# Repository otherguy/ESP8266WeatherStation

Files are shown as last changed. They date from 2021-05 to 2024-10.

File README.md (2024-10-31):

# 🌤 ESP8266 Weather Station

## Hardware

### Bill of Materials (BOM)

The following components are required (all through hole):

| Qty. | Item | Value | Label | Footprint | Price |
|---|---|---|---|---|---|
| 1 | ESP8266 NodeMCU v3 board (4MB flash) | - | | - | US$ 2.05 |
| 3 | MAX7219 8×8 SPI LED matrix | - | | - | US$ 3.14 |
| 1 | DC Female Power Socket | 5.5 × 2.1mm | `J1` | PTH | US$ 0.07 |
| 1 | Trimmer potentiometer | 3mm, 1kΩ | `R1` | DIP-3 PTH | US$ 0.04 |
| 1 | LED | green, 3mm | `LED1` | THT | US$ 0.02 |
| 1 | LED | yellow, 3mm | `LED2` | THT | US$ 0.02 |
| 1 | Resistor (axial) | 4.7kΩ, ¼W, ±5% | `R2` | THT | US$ 0.01 |
| 2 | Resistor (axial) | 100Ω, ¼W, ±5%  | `R3`, `R4` | THT | US$ 0.01 |

I used [RobotDyn yellow/amber colored modules](https://www.aliexpress.com/item/32732745628.html). A lot
of other modules will also work, but they need to be 5-pin SPI chainable modules. Be aware of the pinout!

For the ESP8266 board, I used a [KeyeStudio NodeMCU](https://www.aliexpress.com/item/32668574859.html) but any
other NodeMCU V2 or V3 board also works.

The knockoff V3 boards are better because they use a CH340 USB controller chip and have the `A0` pin reference
voltage set at `3.3V` instead of `1.0V`, meaning no voltage divider circuit is needed.

### Circuit Board

The circuit board is very simple and just holds the ESP8266 and the 3 LED matrices as
well as the power jack and a trimpot to adjust the LED brightness.

I had 10 boards (1.6mm FR4 ENIG, RoHS, black solder mask) manufactured by [JLPCB](https://jlcpcb.com) for
US$ 44.00 including shipping in April 2021. The black solder mask makes it easy to prevent reflections inside
the case (and it looks gorgeous).

The [Fritzing file](hardware/NodeMCUWeatherStation.fzz) as well as the exported
[Gerber files](hardware/NodeMCUWeatherStation_Gerber.zip) can be found in the [hardware](hardware) folder.

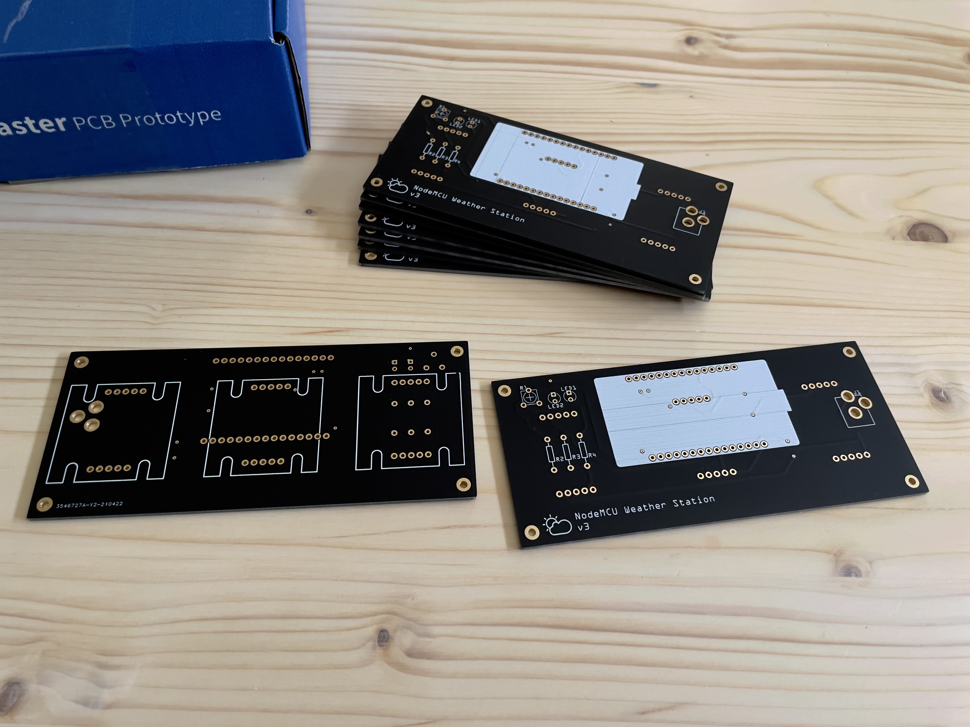
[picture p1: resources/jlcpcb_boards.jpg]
Finished PCB JLCPCB Finished PCB


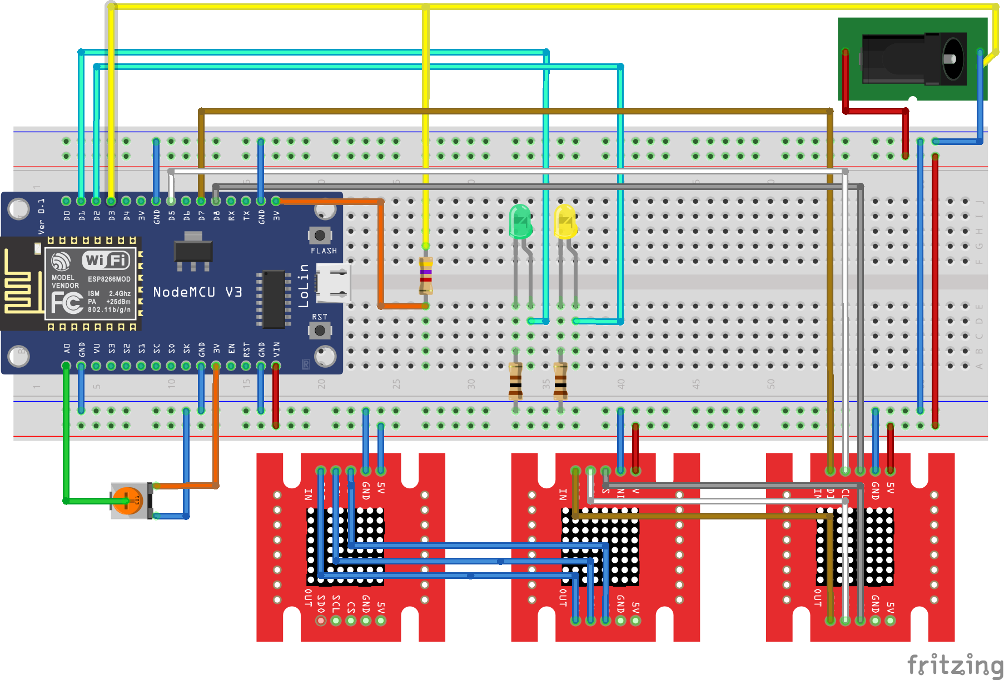
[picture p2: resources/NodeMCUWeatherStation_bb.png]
Breadboard View


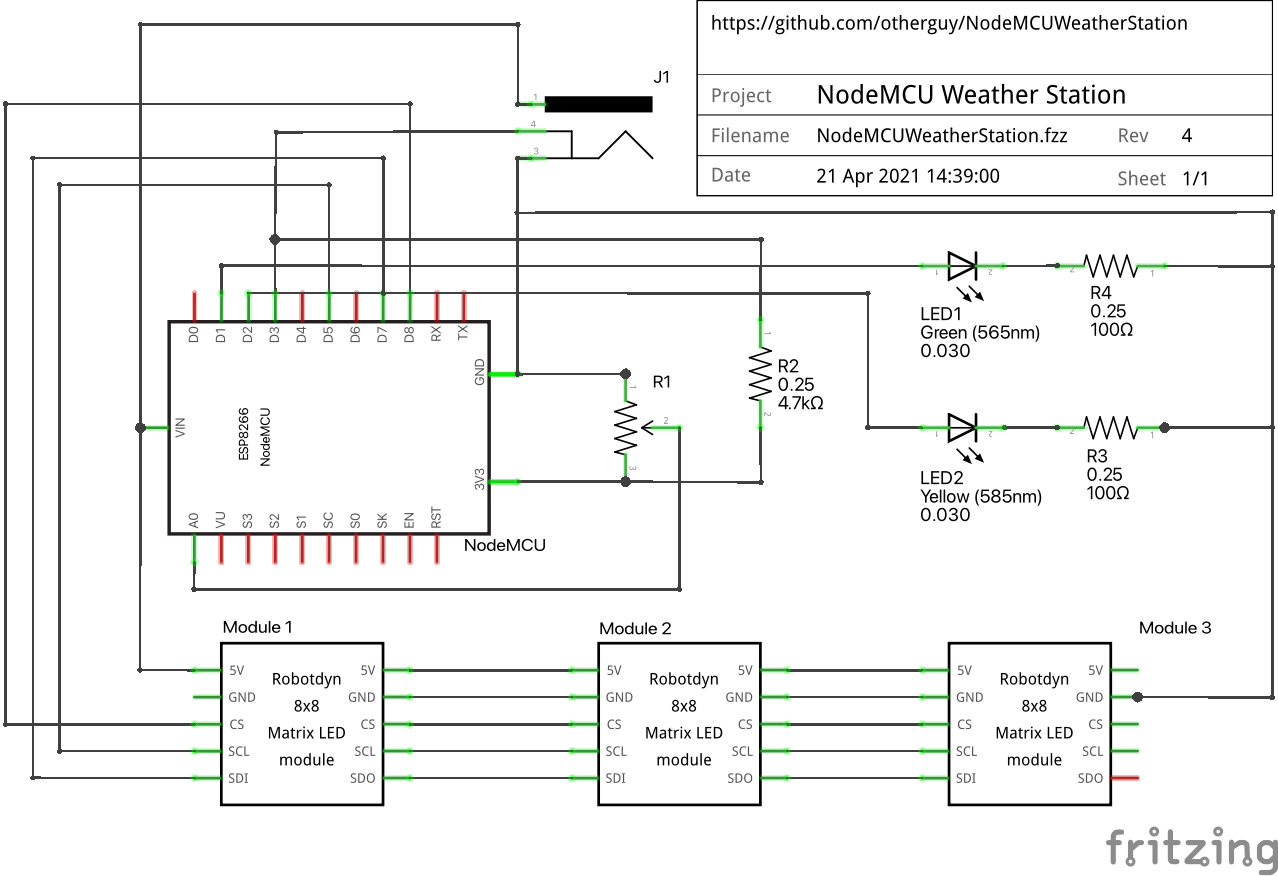
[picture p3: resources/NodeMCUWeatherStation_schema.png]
Schema View


The [`robotdyn-max7219-LED-matrix.fzpz`](hardware/robotdyn-max7219-LED-matrix.fzpz) Fritzing part was made
by [`@vanepp`](https://forum.fritzing.org/u/vanepp) on the Fritzing forums.

### Outer Case

[TBD]

## Software

### Prerequisites

Install [`esptool`](https://github.com/espressif/esptool) and [`ampy`](https://github.com/scientifichackers/ampy).

```bash
$ pip3 install --user esptool
$ pip3 install --user adafruit-ampy
```

### Install MicroPython

Download the latest [MicroPython firmware for ESP8266](https://micropython.org/download/esp8266/) and flash it to the NodeMCU.
[`esp8266-20220117-v1.18.bin`](firmware/esp8266-20220117-v1.18.bin) and flash it to the ESP8266.

_Note:_ Since July 2024, when using the OpenWeatherMap API, you need to use a custom build of MicroPython with a larger TLS buffer. See the section below for more details.

_Note:_ The USB serial device (`/dev/tty.usbserial-1430`) will be different, depending on your operating
system, USB controller and port you use.

```bash
$ esptool.py --port /dev/tty.usbserial-1430 erase_flash
$ esptool.py --port /dev/tty.usbserial-1430 --baud 460800 write_flash --flash_size=detect -fm dio 0x00 firmware/ESP8266_GENERIC-20240602-v1.24.0.bin
```

### Workaround for TLS buffer overflow in axtls

OpenWeatherMap switched to a new SSL certificate in July 2024 which is too large for the default buffer size in the ESP8266's MicroPython TLS implementation with axTLS. This causes the ESP8266 to crash when trying to fetch weather data.
To address this, the buffer size needs to be increased by recompiling the firmware with appropriate settings. More
details can be found in [this GitHub issue](https://github.com/micropython/micropython/issues/3279).

I have provided a precompiled firmware image with the necessary changes in the [firmware](firmware) folder. The firmware
is based on MicroPython `1.24.0` and has a larger TLS buffer size of 8192 bytes. Simply use the [`ESP8266_GENERIC-20240602-v1.24.0-tls-buffer-8192.bin`](firmware/ESP8266_GENERIC-20240602-v1.24.0-tls-buffer-8192.bin)
file instead of [`ESP8266_GENERIC-20240602-v1.24.0.bin`](firmware/ESP8266_GENERIC-20240602-v1.24.0.bin).

You can also compile the firmware for ESP8266 yourself with the following steps:

```bash
gh repo clone micropython/micropython
cd micropython
git checkout v1.24.0
make -C ports/esp8266 submodules
docker run --rm -v $HOME:$HOME -u $UID -w $PWD -e GIT_DISABLE_UNTRACKED_CACHE=1 larsks/esp-open-sdk make -j8 -C mpy-cross
cd ports/esp8266
docker run --rm -v $HOME:$HOME -u $UID -w $PWD -e GIT_DISABLE_UNTRACKED_CACHE=1 larsks/esp-open-sdk make -j8 AXTLS_DEFS_EXTRA="-Dabort=abort_ -DRT_MAX_PLAIN_LENGTH=1024 -DRT_EXTRA=8192" BOARD="ESP8266_GENERIC"
```

The firmware can then be found at `build-ESP8266_GENERIC/firmware.bin`.

### Configure Settings

Edit [`secrets.py`](src/secrets.py) and configure the values for your WiFi network (`WIFI_SSID` and `WIFI_PASSWORD`).

Next, sign up for a free account on [OpenWeather](https://openweathermap.org/), generate
[an API key](https://home.openweathermap.org/api_keys) and set it in the `OW_API_KEY` constant in [`secrets.py`](src/secrets.py).

Find the location you want to display weather data for on [OpenWeather](https://openweathermap.org/) and set the
`GEO_NAME`, `GEO_LAT` and `GEO_LON` constants in [`secrets.py`](src/secrets.py). `GEO_NAME` is not really used at the
moment, so it's only a reminder for you so you know what place you're looking at.

`DISPLAY_OFF_START` and `DISPLAY_OFF_END` are used to control when the display is turned off, e.g. at night. The value
is the hour in 24-hour format, in UTC. Adjust accordingly. If you're in New York City and you want the display to turn
off from 11pm to 7am, you might want to set `DISPLAY_OFF_START` to `3` and `DISPLAY_OFF_END` to `11`. Set both values
to `0` if you never want to turn off the display.

### Upload Software

Use [Adafruit's `ampy` tool](https://github.com/adafruit/ampy) to upload the software to the ESP8266. Adjust the
port according to your operating system and USB controller.

```bash
$ ampy --port /dev/tty.usbserial-1430 --baud 115200 put src/boot.py
$ ampy --port /dev/tty.usbserial-1430 --baud 115200 put src/max7219.py
$ ampy --port /dev/tty.usbserial-1430 --baud 115200 put src/symbols.py
$ ampy --port /dev/tty.usbserial-1430 --baud 115200 put src/secrets.py
$ ampy --port /dev/tty.usbserial-1430 --baud 115200 put src/main.py
```

## Other

### Trimmer Potentiometer

The trimmer potentiometer at `R1` is used to adjust the brightness of the display. The brightness is always
forced to be at the lowest value when the power jack is unplugged. Whe `DISPLAY_OFF_START` and `DISPLAY_OFF_END`
are set to any other value than `0`, the display will be turned off during the specified time period and the
potentiometer value is ignored.

### LEDs

`LED 1` is used to indicate network activity, while connecting to WiFi or fetching weather data.

`LED 2` is used for debugging purposes. It blinks every 2 seconds (or whatever you set in `BLINK_DELAY`). If it
does not blink, it means that the display is not updating and the ESP8266 has locked up.

### Weather Icons

The weather icons were custom designed using this excellent [LED Matrix Editor](https://git.io/J3N9M).

Weather Icons Custom Weather Icons: #185a66bddb663c00|894218bc3d184291|001ea1a919a6c0ec|00007e818999710e|152a547e8191710e|0a04087e8191710e|55aa55aa55aa55aa|a542a51818a542a5|180018183c3c1800|1800183860663c00

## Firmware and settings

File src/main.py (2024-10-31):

# -*- coding: utf-8 -*-
#
# main.py
#
from machine import Pin, Signal, SPI, reset, ADC
from utime import sleep, ticks_ms, localtime
from max7219 import Matrix8x8
from network import WLAN, STA_IF
from ntptime import settime
import secrets
import symbols
import urequests as requests
import gc

# #############################################################################
# ### Configuration
# #############################################################################
#
# This is fairly static and does not need to be changed when deploying.
#

# How often to check for weather updates (milliseconds)
QUERY_DELAY   = 1800000 # 30 minutes

# How often to blink the LED (milliseconds)
BLINK_DELAY   =   30000 # 30 seconds

# How many failed attempts to fetch weather before displaying an error
FAILURE_THRESHOLD = 5

# Definitions
NUM_MATRICES  = 3  # How many 8x8 matrices are connected
CS_PIN        = 15 # GPIO 15 = D8 = CS
LED_0_PIN     = 2  # GPIO  2 = internal LED of the ESP8266
LED_1_PIN     = 5  # GPIO  5 = D1
LED_2_PIN     = 4  # GPIO  4 = D2
INSERTION_PIN = 0  # GPIO  0 = D3
SPI_BAUDRATE  = 10000000 # 10Mhz baudrate (default is 80Mhz)

# #############################################################################
# #############################################################################
# #############################################################################

# Fn: remap()
def remap(value, out_min=0.0, out_max=1.0, in_min=0.0, in_max=1024.0):
    """
    Maps a value from a given range (default 0-1024) to a new
    range (default 0.0 - 1.0). Works with int and float values.

    :param value:    The value to remap
    :param out_min:  The lower end of the output range
    :param out_max:  The upper end of the output range
    :param in_min:   The lower end of the input range
    :param in_max:   The upper end of the output range

    :return: The remapped value
    """
    return float(min(out_max, max(out_min, (float(value) - in_min) * (out_max - out_min) / (in_max - in_min) + out_min)))

# Fn: set_matrix_brightness()
def set_matrix_brightness(pot, display, old_brightness_value, min_brightness=0, max_brightness=15):
    """
    Fetches the daily weather forecast for a given
    location from OpenWeatherMap.

    :param pot:                  The trim potentiometer object to read the analog value from
    :param display:              The LED matrix display object to set the brightness on
    :param old_brightness_value: The previous brightness value
    :param min_brightness:       The minimum brightness supported by the LED matrix
    :param max_brightness:       The maximum brightness supported by the LED matrix

    :return: The brightness value

    :see: https://openweathermap.org/api/one-call-api#example
    """

    brightness_value = int(remap(pot.read(), min_brightness, max_brightness))

    if old_brightness_value != brightness_value:
        print("Read " + str(pot.read()) + " from A0, mapped to brightness " + str(brightness_value) + " (old value was " + str(old_brightness_value) + ")")
        display.brightness(brightness_value)

    return brightness_value

# Fn: get_weather()
def get_weather(lat, lon, api_key):
    """
    Fetches the daily weather forecast for a given
    location from OpenWeatherMap.

    :param lat:     Latitude of the location for which you want the forecast
    :param lon:     Longitude of the location for which you want the forecast
    :param api_key: API Key for [OpenWeatherMap](https://openweathermap.org)

    :return: response object

    :see: https://openweathermap.org/api/one-call-api#example
    """
    request_url = 'https://api.openweathermap.org/data/3.0/onecall' + \
        '?lat=' + str(lat) + \
        '&lon=' + str(lon) + \
        '&appid=' + str(api_key) + \
        '&exclude=current,minutely,hourly,alerts' + \
        '&units=metric' + \
        '&lang=en'

    try:
        response = requests.get(request_url)

        # If the response was not successful, return
        if response.status_code != 200:
            print("Weather API error:", str(response.status_code))
            return None

        # Get daily forecast part
        json_data = response.json()['daily']

        # Return just the daily forecasts for the next 3 days (memory reasons)
        return [ json_data[0], json_data[1], json_data[2] ]
    except Exception as err:
        print ("Exception in request:", err.__class__.__name__, err)
        raise err



# Map from OpenWeatherMap 'Main' conditions to 8x8 icons
# https://openweathermap.org/weather-conditions#Weather-Condition-Codes-2
conditions_map = {
    'Thunderstorm': 'CONDITIONS_STORM',
    'Drizzle':      'CONDITIONS_RAIN',
    'Rain':         'CONDITIONS_RAIN',
    'Snow':         'CONDITIONS_SNOW',
    'Mist':         'CONDITIONS_FOG',
    'Smoke':        'CONDITIONS_FOG',
    'Haze':         'CONDITIONS_FOG',
    'Dust':         'CONDITIONS_FOG',
    'Fog':          'CONDITIONS_FOG',
    'Sand':         'EXCLAMATION_MARK',
    'Ash':          'EXCLAMATION_MARK',
    'Squall':       'EXCLAMATION_MARK',
    'Tornado':      'EXCLAMATION_MARK',
    'Clear':        'CONDITIONS_SUNNY',
    'Clouds':       'CONDITIONS_CLOUDY'
}

# #############################################################################
# #############################################################################
# #############################################################################

# Declarations
spi     = SPI(1, baudrate=SPI_BAUDRATE, polarity=0, phase=0)
display = Matrix8x8(spi, Pin(CS_PIN, Pin.OUT), NUM_MATRICES)
wifi    = WLAN(STA_IF)
pot     = ADC(0)

# Leds
led_0 = Signal(LED_0_PIN, Pin.OUT, invert=True)
led_2 = Signal(LED_2_PIN, Pin.OUT, invert=False)
led_1 = Signal(LED_1_PIN, Pin.OUT, invert=False)

# Insertion detection
insertion = Signal(INSERTION_PIN, Pin.IN)

# Read brightness from trim pot at A0 and set it
brightness = set_matrix_brightness(pot, display, 0)

# Draw WiFi symbol
led_0.on()
led_2.on()
symbols.draw(symbols.WIFI, matrix=display, display=1, clear=True)
sleep(0.5)

# Enable garbage collector
gc.enable()

# Connect to WiFi
if not wifi.isconnected():
    print("Connecting to WiFI '" + secrets.WIFI_SSID + '"')
    wifi.active(True)
    wifi.connect(secrets.WIFI_SSID, secrets.WIFI_PASSWORD)
    while not wifi.isconnected():
        pass

    print('WiFi connected. Local IP: ', wifi.ifconfig()[0])

# Print free memory
print("Free memory: " + str(gc.mem_free()) + " bytes.")

# Set two timer
update_time = ticks_ms() - QUERY_DELAY
blink_time  = ticks_ms() - BLINK_DELAY

# Turn off all LEDs
led_2.off()
led_1.off()
led_0.off()

# Set time from NTP server
print('Setting time from NTP...')
try:
    settime()
except OSError as error:
    print('Failed to set time from NTP: ' + str(error))
    pass
print('Now: {}'.format(localtime()))

# #############################################################################

# Main loop
while True:

    # Prepare a failure counter
    failure_count = 0

    # If power jack is removed, lower brightness
    if insertion.value() == 0:
        display.brightness(0)
    else:
        # Read brightness from trim pot at A0 and set on display
        brightness = set_matrix_brightness(pot, display, brightness)

    # Turn off the display at night (if configured)
    current_hour = localtime()[3]
    if(current_hour >= secrets.DISPLAY_OFF_START or current_hour < secrets.DISPLAY_OFF_END):
        # If we're in night mode, turn off the display
        display.off()
    else:
        # If the display was off, turn it on and reset update_time to trigger a refresh
        if display.is_off():
            display.on()
            update_time = ticks_ms() + QUERY_DELAY

    # If we lose WiFi connection, reboot ESP8266
    if not wifi.isconnected():
        symbols.draw(symbols.WIFI, matrix=display, display=1, clear=True)
        sleep(3)
        print("WiFi disconnected, resetting.")
        led_2.on()
        led_1.on()
        sleep(1)
        reset()

    # Query and get weather JSON every QUERY_DELAY ms
    if ticks_ms() - update_time >= QUERY_DELAY:
        # Turn on LED
        led_1.on()

        # Set time from NTP server
        print('Setting time from NTP...')
        try:
            settime()
        except OSError as error:
            print('Failed to set time from NTP: ' + str(error))
            pass
        print('Now: {}'.format(localtime()))

        print('Fetching weather for ' + secrets.GEO_NAME + '...')
        try:
            weather = get_weather(secrets.GEO_LAT, secrets.GEO_LON, secrets.OW_API_KEY)
            print("Fetched weather successfully")

            # Clear failure counter
            failure_count = 0

        except Exception as err:
            print("Failed to fetch weather!")
            failure_count += 1
            weather = None

        # If the response failed FAILURE_THRESHOLD times, display ! ! !
        if weather == None and failure_count >= FAILURE_THRESHOLD:
            print("Failed to fetch weather " + str(FAILURE_THRESHOLD) + " times!")

            # Clear display
            display.fill(0)

            if not display.is_off():
                # Loop: 0, 1, 2
                for day in range(0, NUM_MATRICES):
                    symbols.draw(symbols.EXCLAMATION_MARK, matrix=display, display=day)

            # Display symbols
            display.show()

        # If the response was successful, update the LED matrices
        if weather != None:

            # Clear display
            display.fill(0)

            if not display.is_off():
                # Loop: 0, 1, 2
                for day in range(0, NUM_MATRICES):
                    condition = weather[day]['weather'][0]['main']
                    symbol_name = conditions_map.get(condition, symbols.QUESTION_MARK)
                    print("Day " + str(day) + ": " + condition + ' (' + symbol_name + ')')
                    symbol_data = getattr(symbols, symbol_name)
                    symbols.draw(symbol_data, matrix=display, display=day)

            # Display symbols
            display.show()

        # Turn off LED
        led_1.off()

        # Clean up
        response  = None
        condition = None

        # Collect garbage
        gc.collect()

        # Print free memory
        print("Free memory: " + str(gc.mem_free()) + " bytes.")

        # Reset update time
        update_time = ticks_ms()

    # Blink LED 2 led if BLINK_DELAY ms have passed since last blink
    if ticks_ms() - blink_time >= BLINK_DELAY:
        led_2.on()
        sleep(0.05)
        led_2.off()
        blink_time = ticks_ms()

    # Sleep
    sleep(0.1)

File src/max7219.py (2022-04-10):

"""
MicroPython max7219 cascadable 8x8 LED matrix driver
https://github.com/mcauser/micropython-max7219

MIT License
Copyright (c) 2017 Mike Causer

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
from micropython import const
import framebuf

_NOOP = const(0)
_DIGIT0 = const(1)
_DECODEMODE = const(9)
_INTENSITY = const(10)
_SCANLIMIT = const(11)
_SHUTDOWN = const(12)
_DISPLAYTEST = const(15)

class Matrix8x8:

    # Start with display turned on
    display_on = True

    def __init__(self, spi, cs, num):
        """
        Driver for cascading MAX7219 8x8 LED matrices.

        >>> import max7219
        >>> from machine import Pin, SPI
        >>> spi = SPI(1)
        >>> display = max7219.Matrix8x8(spi, Pin('X5'), 4)
        >>> display.text('1234',0,0,1)
        >>> display.show()

        """
        self.spi = spi
        self.cs = cs
        self.cs.init(cs.OUT, True)
        self.buffer = bytearray(8 * num)
        self.num = num
        fb = framebuf.FrameBuffer(self.buffer, 8 * num, 8, framebuf.MONO_HLSB)
        self.framebuf = fb
        # Provide methods for accessing FrameBuffer graphics primitives. This is a workround
        # because inheritance from a native class is currently unsupported.
        # http://docs.micropython.org/en/latest/pyboard/library/framebuf.html
        self.fill = fb.fill  # (col)
        self.pixel = fb.pixel # (x, y[, c])
        self.hline = fb.hline  # (x, y, w, col)
        self.vline = fb.vline  # (x, y, h, col)
        self.line = fb.line  # (x1, y1, x2, y2, col)
        self.rect = fb.rect  # (x, y, w, h, col)
        self.fill_rect = fb.fill_rect  # (x, y, w, h, col)
        self.text = fb.text  # (string, x, y, col=1)
        self.scroll = fb.scroll  # (dx, dy)
        self.blit = fb.blit  # (fbuf, x, y[, key])
        self.init()

    def _write(self, command, data):
        self.cs(0)
        for m in range(self.num):
            self.spi.write(bytearray([command, data]))
        self.cs(1)

    def init(self):
        for command, data in (
            (_SHUTDOWN, 0),
            (_DISPLAYTEST, 0),
            (_SCANLIMIT, 7),
            (_DECODEMODE, 0),
            (_SHUTDOWN, 1),
        ):
            self._write(command, data)

    def brightness(self, value):
        if not 0 <= value <= 15:
            raise ValueError("Brightness out of range")
        self._write(_INTENSITY, value)

    def show(self):
        for y in range(8):
            self.cs(0)
            for m in range(self.num):
                self.spi.write(bytearray([_DIGIT0 + y, self.buffer[(y * self.num) + m]]))
            self.cs(1)

    def on(self):
        self.display_on = True
        self.show()

    def off(self):
        self.display_on = False
        self.fill(0)
        self.show()

    def is_off(self):
        return not self.display_on

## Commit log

2021-05-04 Update board to V4
    [NodeMCUWeatherStation.fzz]
2021-05-09 Add finished board photo
2021-05-09 Update board images
    [NodeMCUWeatherStation.fzz]
2021-05-09 Create BOM
2021-05-09 Update board
    [NodeMCUWeatherStation.fzz]
2022-04-10 Add timer to turn off the display
2022-04-10 Update for switching off display
2024-08-13 Show exclamation marks on error
    [main.py]
